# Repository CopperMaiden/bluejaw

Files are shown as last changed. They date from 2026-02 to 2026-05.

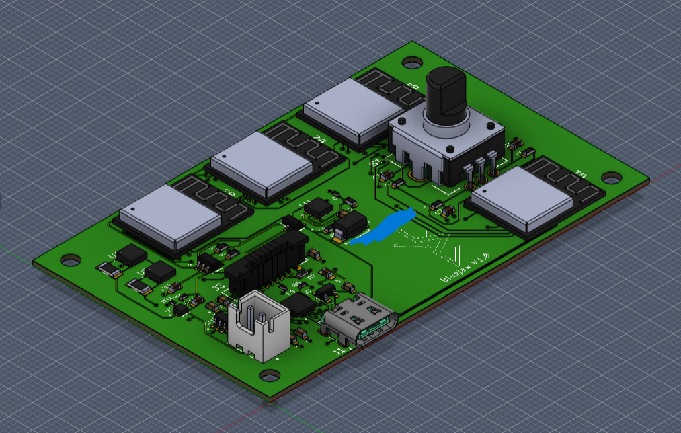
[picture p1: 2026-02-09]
Images/Screenshot 2026-02-08 093432.png

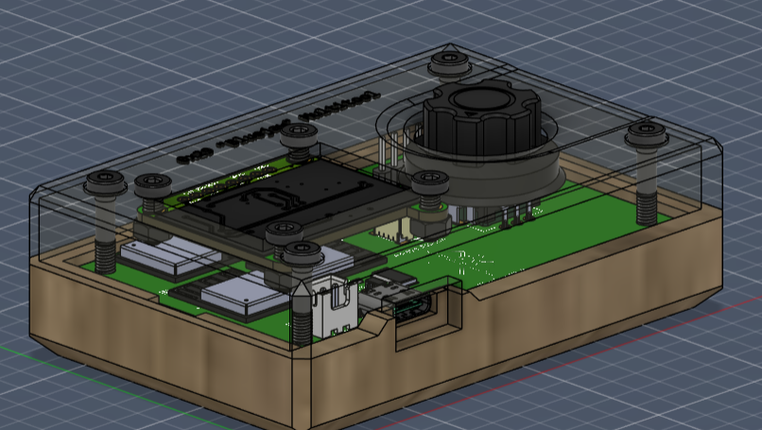
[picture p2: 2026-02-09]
Images/image.9png.png

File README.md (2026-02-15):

# BLUEJAW
Multi-client Bluetooth sharing device with a mass of QOL features, all packed into the size of an Altoids tin

Hello !
To clear up any confusion, 0x29 is just one of my aliases. This device is of my own design, yet I'm flexible regarding the public's consumption or adaptations of it. Open source is love <3.

This project is dedicated to my partner and made possible by the HackClub organization. (WEBSITE: https://hackclub.com/, © 2026 Hack Club. 501(c)(3) nonprofit (EIN: 81-2908499))

In-Progress Cad Model of Physical Design & Logo

# FILE GUIDE

```
/Documentation - All project documentation is stored here as markdown files
/Firmware-&-Software - Any files pertaining to the firmware or otherwise code written for the device
/Images - All images or screenshots taken during the course of designing this project
/Models - Any 3D models associated with the project
/PCB - GERBER file for the BLUEJAW V1.0 PCB
```

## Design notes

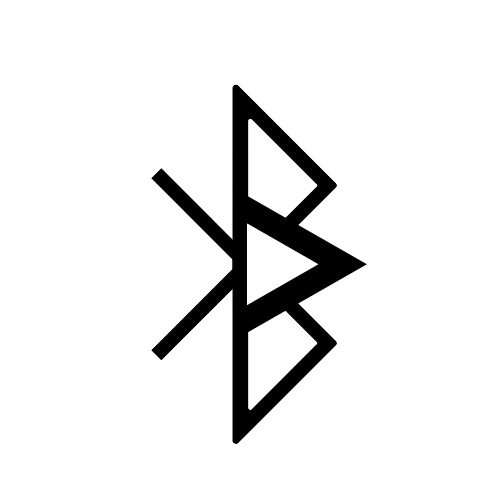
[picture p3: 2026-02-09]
Images/Untitled_design-removebg-preview.png

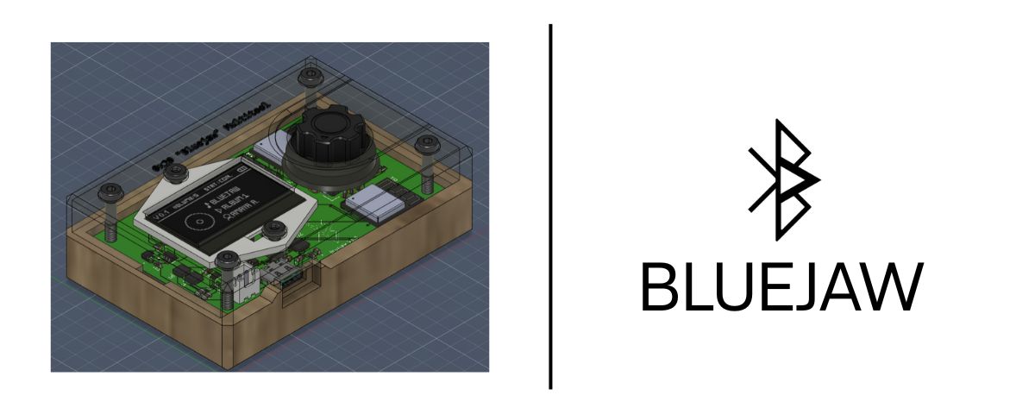
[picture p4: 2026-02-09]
Images/BLUEJAW(3).jpg

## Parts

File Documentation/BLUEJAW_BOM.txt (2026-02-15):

Partlist exported from PCB v138 at 2/15/2026 1:18 PM

Reference Designators          Quantity Description Package                   Value                          Manufacturer              Manufacturer Part Number Vendor Vendor Part Number Top/Bottom 
                               1        PCB Board   Board                                                                                                                                            
B1, B2, B3, B4                 4                    XCVR_ESP32-C3-MINI-1-N4   ESP32-C3-MINI-1-N4             Espressif Systems                                                            Top        
C1, C2, C10, C13               4                    CAPC1608X90N              CL10B105KP8NNNC                Samsung Electro-Mechanics                                                    Top        
C3, C9, C11                    3                    CAPC1608X90N              CL10A106KP8NNNC                Samsung Electro-Mechanics                                                    Top        
C5                             1                    CAPC1608X90N              CL10A475KP8NNNC                Samsung Electro-Mechanics                                                    Top        
C6                             1                    CAPC1608X90               C0603C104K5RACTU               KEMET                                                                        Top        
C7, C8, C12, C14, C15          5                    CAPC1608X90N              C0603C104K5RAC7411             Kemet                                                                        Top        
CH1                            1                    SOT95P280X145-5N          MCP73811T-420I/OT                                                                                           Top        
CR1                            1                    CR_SMA_403AE_OSI          SS14CR_SMA_403AE_OSI                                                                                        Top        
D1                             1                    SOT143                    SP0503BAHTG                                                                                                 Top        
J1                             1                    AMPHENOL_12402012E212A    12402012E212A                  Amphenol                                                                     Top        
J2                             1                    JST_B2B-XH-A              B2B-XH-A                       JST Sales America Inc.                                                       Top        
J3                             1                    AMPHENOL_F31W-1A7H1-11016 F31W-1A7H1-11016               Amphenol                                                                     Top        
MOSFET1                        1                    MICRO3_SOT23_INF          IRLML6401TRPBFMICRO3_SOT23_INF                                                                              Top        
R1, R6, R8, R10, R15, R16, R17 7                    RESC1607X60N              RC0603FR-0710KL                                                                                             Top        
R2                             1                    RESC1005X40N              CRGCQ0402F82K                                                                                               Top        
R3, R4                         2                    RES_ERA2AEB512X           ERA2AEB512X                    Panasonic                                                                    Top        
R5                             1                    RES_ERA2AEB102X           ERA2AEB102X                    Panasonic                                                                    Top        
R7                             1                    RES_ERJ-3GEYJ684V         ERJ-3GEYJ684V                  Panasonic                                                                    Top        
R9                             1                    RES_ERA2ARC512X           ERA2ARC512X                    Panasonic                                                                    Top        
R11                            1                    RES_ERA2AEB222X           ERA2AEB222X                    Panasonic                                                                    Top        
R12                            1                    RC0402FR-07330RL          RC0402FR-07330RL                                                                                            Top        
R13, R14                       2                    RESC3216X50N              RG3216P-5004-B-T1                                                                                           Top        
S1                             1                    XDCR_PEC12R-4215F-S0024   PEC12R-4215F-S0024             Bourns                                                                       Top        
U1                             1                    AMPHENOL_12402012E212A    LD39200PU33R                   ST Microelectronics                                                          Top        
U2                             1                    QFN50P400X400X80-25N      CP2102N-A02-GQFN24R            Silicon Labs                                                                 Top        
U3                             1                    SON50P150X150X80-6N       BQ29700DSER                    Texas Instruments                                                            Top        
U4, U5                         2                    TRANS_CSD16406Q3          CSD16406Q3                                                                                                  Top        
U6                             1                    SOT-23-5_MC_MCH           MCP3021A0T-E/OTSOT-23-5_MC_MCH                                                                              Top

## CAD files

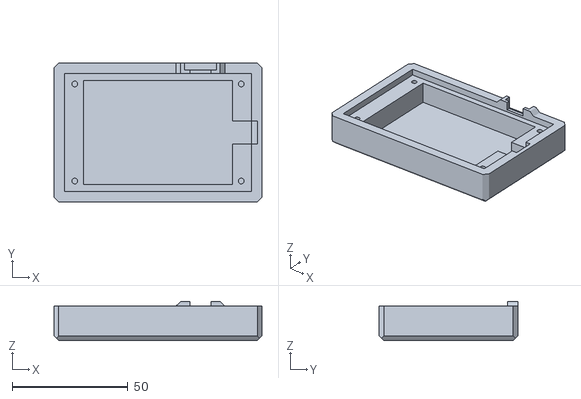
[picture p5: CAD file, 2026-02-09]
Models/BottomCase/bottomcasing.stl
90.0 x 60.0 x 16.9

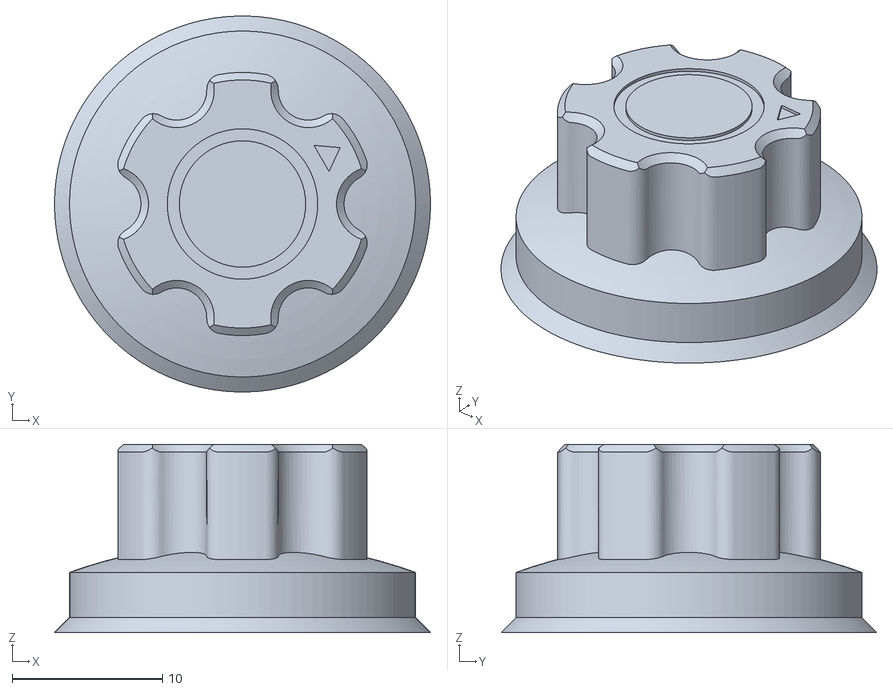
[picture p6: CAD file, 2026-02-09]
Models/Misc/BluejawInterfaceKnob.stl
25.0 x 25.0 x 12.5

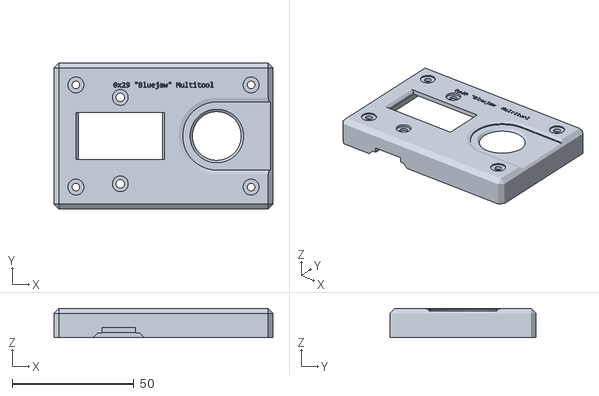
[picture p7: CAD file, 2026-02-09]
Models/TopCase/topcasing.stl
90.0 x 60.0 x 12.0

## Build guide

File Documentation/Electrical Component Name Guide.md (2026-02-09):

### All component names and their identification/serial numbers are listed below. 
(Project BLUEJAW by Amaya Allison: https://github.com/CopperMaiden/bluejaw)

---
- "12402012E212A" - USB C receptacle

- "B2B-XH-A" - JST 2 pin connector
- "BM04B-SRSS-TB" - JST 4 pin connector

- "CL10B105KP8NNNC" - CAP CER 1UF 10V X7R 0603
- "CL10A106KP8NNNC" - CAP CER 10UF 10V X5R 0603
- "C0603C104K5RAC7411" - CAP CER 0.1UF 50V X7R 0603
- "CL10A106KP8NNNC" - CAP CER 10UF 10V X5R 0603

- "ERA2AEB512X" - RES SMD 5.1K OHM 0.1%
- "ERA3AEB122V" - RES SMD 1.2K OHM 0.1%
- "RPC2512JT470R" - RES 470 OHM 5%
- "RC0603FR-0710KL" - 10 kOhms ±1% 0.1W, 1/10W Chip Resistor
- "CRGCQ0402F82K" - RES 82K OHM 1% 1/16W 0402
- "ERA-2AEB102X"  - RES SMD 1K OHM 0.1% 1/16W 0402
- "RC0603FR-0710KL" - RES 10K OHM 1% 1/10W 0603
- "ERJ-3GEYJ684V" - RES SMD 680K OHM 5% 1/10W 0603
- "ERA-2ARC512X" - RES SMD 5.1KOHM 0.25% 1/16W 0402
- "ERA-2AEB222X" - RES SMD 2.2K OHM 0.1% 1/16W 0402
- "RC0402FR-07330RL" - RES 330 OHM 1% 1/16W 0402
- "RG3216P-5004-B-T1" - RES 5M OHM 0.1% 1/5W 0805

- "ESP32-C3-MINI-1-N4" - Cmon... (minor alternative to common controllers, perfect for project)

- "MCP73811T-420I_OT" - IC BATT CNTL LI-ION 1CEL SOT23-5

- "PEC12R-4215F-S0024" - ENCODER INCRE QUAD HORIZN PC PIN

- "SOT_619TA_DIO" or "FMMT619TA" - TRANS NPN 50V 2A SOT-23-3

- "LD39200PU33R" - LINEAR VOLTAGE REGULATOR (3.3 VOLTS)

- "SP0503BAHTG" - TVS DIODE 5.5VWM 8.5VC SOT1434

- "IRLML6401TRPBF" - MOSFET P-CH 12V 4.3A SOT23

---

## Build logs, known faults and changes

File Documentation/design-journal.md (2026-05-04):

<!--
  This journal is auto generated by Hack Club Blueprint.
-->

# 2/9/2026 - Created Poster for Device  

_Time spent: 2.0h_  

Created a poster after being requested to display this project at my Highschool. The poster is attached below.

Poster

I do not have logs preceding this one, since this project had to be restarted from a prior repository. The change left a large gap in uploaded documentation, but I logged my progress elsewhere (discord channel), and will dedicate the next few days of work to transferring those updates here (while I wait for this project's PCB to arrive).  

# 2/10/2026 - Rotated assembly and shortened casing  

_Time spent: 4.3h_  

### Personal log:
I ended up having to make a redesign to the upper shell and the display tray to prevent the knob from being inaccessible, as well as effectively reduce the overall profile of the device, since it was spacially ineffecient before this revision.

# Height reduction
These images demonstrate the height reduction achieved by the redesigned upper half of the casing.



(Measurements from highest to lowest points on upper casing (8mm (new) height v. 12mm (Old) height))


---

# Update to device orientation

As a result, due to collisions, the display had to be rotated, shifting the orientation of the device entirely.


### Collisions:
Screws from display tray (hardware secures display tray to top half of the case)
After reorienting the display tray and rejointing the assembly in CAD, I noticed a glaring issue regarding collisions with components connected to the PCB. Various components would intersect the bottom of screws or nuts without adjustment. To combat this, height reduction was chosen to be done at 2/3 the height of the original top half of the device's case. Additionally, the tray was reduced in profile to avoid collision with the battery connector on the PCB, demonstrated in the image below.

(Second image shows **ORIGINAL** tray design with colliding area circled)

Decals now differ from the horizontal variation of the assembled device in CAD to the vertical variation, designated revision 1 and revision 2, respectively. (first image: revision 1, second image: revision 2).




Lastly, hardware has changed for both the display tray and the four screws securing the top and bottom halves of the device's case.
Revision 1: {Top and bottom screws: M3 x 10mm | Display tray screws: M3 x 8mm}
Revision 2: {Top and bottom screws: M3 x 6mm | Display tray screws: M3 x 14mm}

# Conclusion
The revisions were necessary to reduce the overall size of the device, but they leave room for concern. For instance, the display is now rotated 90 degrees from the connector on the PCB, which could damage the display's FPC is there is too much stress put on it during assembly. Further issues should be investigated. I will also continue to add previous design history over the course of the next few days. The PCB for bluejaw has been produced at the factory and will be ready for soldering after funding is secured for the project (since components must be ordered).  

# 2/11/2026 - PCB Design Summary (A little over 1 month)  

_Time spent: 55.0h_  

# Introduction
Accidentally, I had not stored my documentation on this platform, acting against the instruction all participants recieved for the Blueprint event. I made this mistake because I believed that the project's complexity would make it near impossible to finish given the original deadline, however I worked on it nonetheless. Now that the deadline seems feasible again, I have re-entered this event with a stricter set of goals and a half-finished device (conceptually; missing firmware).

This journal entry accounts for the roughly 2 month long period of design I allocated to creating a PCB. As of today, 2/11/2026, there is no changes to be made to the PCB of the device. The board has been ordered and is in transit. When funding is secured, the PCB can be assembled with it's necessary components.

---

The following image is verifiable proof of the date of creation for the PCB.


---

# Week 1 (Estimated ~12 hours)

With the initial design concept in mind, I took to wikipedia to research the bluetooth protocol, [found here](https://en.wikipedia.org/wiki/Bluetooth). I learned that there would need to be multiple devices with a bluetooth implementation in order for there to be multiple outputs for audio sharing. That limitation lead me to search through the electronics component distributing company, Digikey. 

In my mind, the design would center around, initially, only 3 bluetooth capable modules, which would all be made portable via a rechargeable battery. For a small, portable device, the bluetooth modules needed to meet the following criteria: 
- Energy efficient 
- Reliable 
- Tiny
- Built in microcontroller (to handle peripherals and peer communication)
- Low cost

! NOTE: (Postscript) I incorrectly recount my experience in the paragraph proceeding this note. I originally believed an RP2040 chip was the ideal microcontroller to drive the ESP-32 modules, before eventually learning that the ESP-32 modules were fully capable of acting as their own microcontrollers. END OF NOTE. !

With all of the criteria in mind, I ended up selecting the "ESP-32 C3 MINI 1 N4", a capable microcontroller with bluetooth and wifi, all in an SMD package that could interface with a PCB nicely.
MFG_ESP32-C3-MINI-1

The ESP-32 C3 draws between 290mA ~ 350mA at the most, and since there was only 3 of them (at the time), I assumed the maximum draw of current from the battery would be 1050mA, give or take. With a selected PCB size of 80mm by 50mm (about the size of an altoid's tin), the battery would need the following criteria:
- Smaller than 80mm (length) by 50mm (width)
- Near 3.3 Volts (For the ESP-32 C3)
- At least ~2 hours of battery life when running at full load

I decided on the MIKROE-1120, a 3.7 volt and 2Ah rechargeable lithium-ion battery (63.5mm x 44.2mm x 7.0mm).
MFG_MIKROE-1120

Using that battery automatically limited me to using a specific JST-style connector to power the ESP-32 modules. I arbitrarily selected the B2B-XH-A, mostly because it was a functional connector for the design's purpose (a JST connector receptacle with a pitch of 0.098" (2.50mm) and two male pins were required).

B2B-XH-A(LF)(SN)

Finally, I'd need to figure out what the user-interface would be. I knew about a cheap oled display from Adafruit, specfically the SH1106G display with the following specs:
- 128x64 resolution
- OLED
- 1.3"
- Monochrome
- SPI communication

It would be a fairly barebones component that would require my own implementation, but the cost of this raw display was significantly cheap compared to it's breakout board alternative, which was also offered by Adafruit (Raw display: $6.50 v. Finished display: $19.95).


To implement the display, I'd need the connector specified by Adafruit to connect it's FPC "ribbon" cable to the PCB of Bluejaw. Adafruit states, "for the matching connector, you'll need a 16-pin 0.5mm pitch FPC flip-lock connector" (https://www.adafruit.com/product/5228).

The connector I selected was not chosen for any other reasons besides matching the qualifications given by Adafruit. The F31W-1A7H1-11016 from Amphenol was the first result that appeared in Digikey's search engine that I found aesthetically pleasing, so I selected it.
F31W-1A7H1-11016

A display gives this device a voice, but the user still cannot interact with it until a peripheral is implemented. That's why I turned to using a rotary encoder for user-input. I searched through Digikey and initially selected the PEC12R-4225F-S0024, since it had a button and seemed relatively small (I would later find out that was not the case).
PEC12R-4217F-S0024
! NOTE: I would learn after importing this component that this image from Digikey was incorrect and highly inaccurate to the product. END OF NOTE !

To charge the battery, I chose a USB-C receptacle (arbitrarily), with the product name 12402012E212A.
12402012E212A

For the last part of the design, I knew that the battery would require some kind of IC for charge management. I searched Digikey for "battery management system" and sourced the BQ29700DSER, an IC capable of managing a single lithium ion cell.
296~4207810~DSE~6

! NOTE: The following image contains the RP2040 referenced in an earlier note. Parts of the initial design are labelled. END OF NOTE. !
anotatedFirstRevision

All of these initial components were then put onto a 80mm by 50mm rectangular PCB to see how they would be positioned.

# Week 2: Implementing major components (Estimated time: ~13 hours)

This week involved trying to integrate the components selected from the previous week to actually function. To provide an analogy, imagine writing bullet points for a creative writing piece and proceeding to flesh out each idea later on, like character names for instance, or how their backstories tie together cohesively.

### Early design of charging circuitry

To start, I tried implementing the battery charging IC by following the recommended schematic provided with it on Digikey. The first thing I did was realize that my charging IC was not, in fact, a charging IC, but instead only a battery protection IC (I would remove it only to add it back later as I realized I would need it in the final device to avoid overcurrent or undercurrent, as well as some other general hazards that come with using a lithium-ion battery.

The component I replaced the battery protection IC with was an IC I believed was capable of charging the circuit. The MCP73811T-420I/OT from Microchip Technology was labelled as a charge controller on Digikey--a component that I researched was capable of managing the current and voltage being provided to the battery during a charge cycle.
150~C04-091~CT,OT~5_web(640x640)

In this version of the PCB, I add in general components recommended by the datasheet, with the addition of a voltage divider to take 5 volts from the USB-C receptacle and turn it into a manageable 3.3 volt signal for the PROG pin on the IC (the pin required by the IC to set the target voltage for the output).


The two capacitors I used to implement the schematic shown above were both CL10B105KP8NNNC capacitors. They had a limit of 10 volts with one microfarad capacitance (per capacitor), the capacitance being the more important specification since it was the recommended schematic's only criteria for the component. Considering these were both used as decoupling capacitors, the 10% +- tolerance in their capacitance was more than negligeable.
Ceramic-Capacitor-CL-Series

As for the resistors, I attempted to find the closest difference in their resistance to still achieve a 3.3 volt output from the divider. The resistors were 470 ohms and 1.2kOhm components, respectively.
The ERA-3AEB122V was 1.2kOhms with a 0.1% tolerance, and the RPC2512JT470R was the 470ohms with 5% tolerance.
Image 1 is the ERA-3AEB122V, image 2 is the RPC2512JT470R:
10-0603 Resistor(1)
2512 (6432 Metric)

Here is an image of the PCB with this stage of implementation:
project1
! NOTE: The image also has traces from the ESP-32 modules linking them to the RP2040, this connection is not of much importance, since it's purely ground connections and linking pins with the same function together (IOVDD repeated multiple times) END OF NOTE. !

Here is an image of previous image's schematic, specifically the charging IC:


### Hardware to program the ESP-32 modules

I knew that at some point, I'd need to add a method to actually flash the firmware I write to the ESP-32 modules so they could function as intended. Since I'd used debugging header pins on previous PCBs for my projects in the past, I decided to use some male header pins that were compatible with most hobbyist breadboard-style jumper wires. My plan was to use some of my existing programming tools, like a CH340 or similar, to program each module.

I landed on a 3 pin male header with 2.54mm pitch, the 61300311121 to be exact:


Why three pins? Well, in my last project, an e-ink display controlled by a simple ATTINY1616-SN microcontroller, I used UPDI, a protocol that required 3 pins. For some reason, based off of no actual fact, I assumed that this would apply to the ESP-32 modules as well. Regardless, I changed the header later on to a 4 pin design to use UART instead. Here's an image of the three pin header on the PCB before we move on:
project2

The four pin header I switched to was not a set product, but rather a package from Fusion 360's default library, mostly as a placeholder until I could settle on a proper solution for programming the ESP-32 modules. I figured it wouldn't matter what specific header I'd purchase since they follow identical soldering footprints. The header was titled "PINHD-1X4" in software by Fusion 360.

At this point, I realized just how little I knew about what I was designing and reached out to a friend of my brother, Hailey. Hailey has a mass of skills that include: embedded circuits, low level programming, and designing PCBs, just to name a few. Hailey assisted me with verifying my ideas and implementations of various parts of the design, essentially acting as a peer reviewer for major aspects or concepts of my design.

---

### Small tangent:
It's a very crucial part of my design philosophy to avoid AI by any means necessary. While the temptation of having an immediate answer to complex questions is strong, so is my regard towards AI in projects like these: I do not believe artificial intelligence should have any presence in a design that is deeply personal to yourself and your own life. Bluejaw means a lot to me, being a project I only thought of and made possible because of my amazing partner. I wanted it to be as genuine and heartfelt as it could be, and for those reasons, I sought help from Hailey to make sure things would go smoothly.

---

You may realize the RP2040 is no longer present in the last image of Bluejaw given in this document, and that's intentional. Hailey pointed out that the ESP-32 was more than capable of acting as it's own microcontroller, so I supplemented the component with another ESP-32, giving the device even more potential for multi-client output. 

Some minor rearrangement of components later, and this was the result:
project4
You may notice two additional components, those are SMD resistors linked to the USB-C receptacle to enable 5V charging & cause the device to act as a sink for power, instead of giving it.


Both of those resistors are ERA2AEB512X resistors, with 5.1kOhm resistance and 0.1% tolerance.
ERAW Series 0402 Pkg

# Weeks 3 + 4: Heavy integration of all components (Estimated time ~20 hours)

At this point, momentum took off with how fast I began to implement each part of the circuit. The project went from a "maybe" into a "I need this done, or else.", and I was (and still am) determined to make the latter work.

There were a few major categories of integration to name here:
- Charging/Battery protection
- Programming solution over UART from USB-C to ESP-32 modules
- ESP-32 peer to peer communication (communication between modules)
- Integrating peripherals (USB-C receptacle, rotary encoder, display connector)

### Charging/Battery protection

A problem exists when both the USB-C receptacle and battery can actively provide power to the restof the circuits at the same time. To fix it, I added a transistor that would cut the battery off whenever power could be supplied from the USB-C port instead. Here's an image of the schematic with that implementation.


But, as you may immediately notice, as did I a few minutes after adding the transistor, it would not function as intended at all. The way that the transistor is wired in this schematic achieves nothing, and only makes the problem worse. For context, the label marked "BAT" is the output that the rest of the circuit would use from the battery as power. If the transistor were implemented as shown in the schematic, it would prevent the battery from providing any power, and additionally have a useless gate that opens to nothing if power is added via the USB-C receptacle. Regardless, I knew I'd need a different cut-off solution, so I moved onto another part of the design to step away and give myself time to think. The transistor I used was the FMMT619TA, picture shown below.
31~SOT23-3~F,N,SA~3

To combat the difference between the battery's 3.7 volts and the USB-C receptacle's 5 volts, a linear regulator was added: an LD39200PU33R. The IC is capable of a 2A output at 3.3 volts, a perfect solution for the device's 3.3 volt requirement from the ESP-32 modules. Previous estimation of current draw from the ESP-32 modules was done with only three modules, but there are four. Current draw from four ESP-32 modules can be estimated with 350mA * 4 = 1400mA, which would be within the limits of the regulator. The 2A output of this linear regulator is not strictly enforced, but rather just a limit. The device would output a steady 3.3 volts for the ESP-32 modules with leeway for additional peripherals (like the display).
497~7946637~~6

Here's an early implementation of the regulator without the battery connected:


The following components are referenced in the schematic above (may not be in the final implementation):
R1 = 10kOhm resistor, part of a voltage divider (RC0603FR-0710KL)
R2 = 82kOhm, also part of a voltage divider (CRGCQ0402F82K)
C3 = 10uF, decoupling cap (CL10A106KP8NNNC)
C4 = 10uF, decoupling cap (CL10A106KP8NNNC)

After realizing my previous error with the regulator, I turned to Hailey for suggestions. She sent me a Hackaday article with many important tips and a wealth of information regarding charging circuits and the general use of lithium ion cells in projects: https://hackaday.com/2022/10/10/lithium-ion-battery-circuitry-is-simple/

The following schematic was recommended as a solution from the article to the charging cut-off problem I recognized previously:
hadimg_liion_electronics_7

I then implemented it with the regulator, as the article suggested, and was left with this completed solution:


The combination of Hailey's advice and the new information I gathered form the Hackaday article taught me that I'd need a few more circuits to prevent any issues with the battery, such as overcharge or undercharge. Simply put, it would charge, but without any safety or protections aside from some loose guardrails.

Back came the single-cell lithium-ion battery protection IC from earlier: The BQ29700DSER


The following components are referenced in the schematic above:
R11 = 2.2kOhm resistors with 0.1% tolerance (ERA2AEB222X) PURPOSE: Recommended by datasheet
R12 = 330Ohm resistor with 1% tolerance (RC0402FR-07330RL) PURPOSE: Recommended by datasheet
R13, R14 = 5MOhm resistors with 0.1% tolerance (RG3216P-5004-B-T1) PURPOSE: Recommended by datasheet (mention in footnote: "The 5-M resistor for an external gate-source is optional.")
C14 = 0.1uF capacitor (C0603C104K5RAC7411) PURPOSE: Recommended by datasheet
U4, U5 = N-Channel mosfet (CSD16406Q3) PURPOSE: Recommended by datasheet

This circuit would help cut the battery off from the rest of the circuit in the case of any of the following faults:
- Over current
- Over/Under voltage
- Short circuit

Recommended circuit from the datasheet:


Lastly, I wanted the device to have some way to indicate to the user when a charge was necessary, and to give myself the opportunity to implement a low-power mode in software to preserve the battery whenever the charge would run low. I learned about analog to digital converters from Hailey and implemented the following circuit:


Connections were made to a child ESP-32 device with the intention of being co0ntrolled by the parent ESP-32 in addressed commands to read the ADC (analog to digital converter). Specific child device in question was designation B2.

The following components are referenced in the schematic above:
C15 = 0.1uF (C0603C104K5RAC7411) PURPOSE: Decoupling capacitor
R16, R17 = 10kOhm resistors with 1% tolerance (RC0603FR-0710KL) PURPOSE: Pull up resistors (Recommended by datasheet)

An analog to digital converter allows the main ESP-32 of Bluejaw to read the change in voltage from the battery as it slowly drops during usage. When the voltage gets lower, the ESP-32 will be able to detect that change via the converter, and the menu can give an estimation for the current capacity/charge of the lithium-ion cell (at max charge battery sits around 4.2 volts, at min battery sits around 2.75 volts (Assumed from battery cut off circuits in datasheet)).

### Programming solution over UART from USB-C to ESP-32 Modules

Taking inspiration from a video I saw (credits to the RF-Clown V2 from CiferTech (https://youtu.be/Jadzrg9bz40?si=hG7vkoj-3Ku74Nmk) https://github.com/cifertech/RF-Clown), I realized that I could use a UART bridge IC to make communication between the USB-C receptacle and the ESP-32 modules possible. Ironically enough, the RF-Clown V2 is a very similar device to Bluejaw, but this is unintentional. The RF-Clown V2 is an elegant design that efficiently utilizes all of it's components; Bluejaw is an idea I got off a whim while with my partner that spiraled into a much larger project than intended. Here is the bridge IC I decided to use after reviewing the schematics from the RF-Clown V2 (CP2102N-A02-GQFN24R):
336~24QFN-,90-4x4~M~24_web(640x640)

And here is an image of the circuit I implemented with the RF-Clown V2 as heavy inspiration (USB-C present):


The following components are referenced in the schematic above (may not be in the final implementation):
R5 = 1kOhm resistor with 0.1% tolerance, (ERA-2AEB102X) PURPOSE: Power supply for IC, recommended by datasheet of IC
R4, R3 = 5.1kOhm resistors with 0.1% tolerance, (ERA-2AEB512X) PURPOSE: Pull down for USB-C, same purpose as mentioned earlier to enable sink from receptacle at 5V
C5 = 4.7uF capacitor (CL10A475KP8NNNC) PURPOSE: Decoupling cap, recommended by datasheet of IC
C6 = 0.1uF capacitor (C0603C104K5RACTU) PURPOSE: Decoupling cap, recommended by datasheet of IC
D1 = diode IC with 1 input, 3 outputs (SP0503BAHTG) PURPOSE: ESD protection diodes, recommended by datasheet of IC
12402012E212A = (USB-C receptacle, mentioned in prior texts of this document)

This will allow me to implement the communication required for the ESP-32 modules in software later, significantly reducing the complexity of translating the datapins of the USB-C receptacle into something usable.

### ESP-32 peer to peer communication (communication between modules)

UART is a more than capable serial communication protocol for this project, with some minor modifications in firmware to give it multi-device capability. While it's slower than I2C or SPI, it works nicely with an IC that helps the USB-C receptacle communicate in UART, reducing the overall complexity I'd have to deal with if I used a different protocol, at least on the hardware side of things.

An early implementation of UART involved connecting each ESP-32 module to a single ESP-32 module that would act as the parent, however, as you will see in the image below, I initially connected all of the transmit and recieve lines together, until I could decide which module was the most ideal to select as the parent with additional components added to the board.


In the final implementation, I used B1 as the parent ESP-32, using the others as secondary modules to recieve commands as child devices.

Child devices are capable of communicating with the parent through unique connections (UART1, UART2, UART3).

The MASTER_UART connections all lead off the parent ESP-32, as it would address each child individually with universal messages. The firmware for each child will be different depending on the presence of peripherals, with individual addresses given by flashing the modules individually before soldering to the PCB. In a later revision, if there is enough funding, I will seek to implement this solution instead, such that individual addressing is easier:


I sadly neglected to make this change before ordering the PCBs with the original connectivity, so this will have to be a decision in the future when funding is available. Just in case, I updated the design in CAD such that this may be an immediate solution to utilize in the case that it becomes necessary:


To share audio reliably, the I2S protocol was implemented for every device with three pins per module. I learned about it while researching serial protocols earlier in the project and thought it might add some nice reliablity to the audio sharing capabilities of the device, such that the UART method of communication would not be over-burdoned. (https://www.digikey.com/en/maker/tutorials/2023/what-is-the-i2s-communication-protocol)

The following pins are required for a minimalistic implementation of I2S, and are the ones I used here:
- BCLK (bit clock)
- LRCLK (left-right clock)
- SD/DIN (serial data/data in/data out)

### Integrating peripherals (USB-C receptacle, rotary encoder, display connector)

The rotary encoder was slightly more challenging to implement, since Hailey and I had a few conversations regarding the matter of having to implement the component from the ground up. Unlike some encoders, the one used in this project would need many external components for reliability and basic function.


It seemed relatively simple to me at first, wire the internal switch to the GPIO of the module, same as the A and B channels of the encoder. But the circuit shown above would not be reliable.
By the later end of designing the PCB, the following circuit was used:


There is a variety of decoupling capacitors and pull up resistors for both the A and B channels, as well as the internal switch of the rotary encoder.

The following components are referenced in the schematic:
R6, R8, R10 = 10kOhm with 1% tolerance, resistors (RC0603FR-0710KL) PURPOSE: Pull up resistors
C7, C8, C12 = 0.1uF, capacitors (C0603C104K5RAC7411) PURPOSE: Decoupling capacitors

Although I struggled to understand how a rotary encoder worked in software, Hailey managed to explain the offset of the A and B channels and how they can be used to determine rotational movement and its direction. Here's an image she sent of her oscilloscope demonstrating the difference between the channels.


Essentially, one channel will make metal on metal contact with the internals before the other during rotational movement, connecting ground to the power supplied at the encoder's channels. Depending on which channel is active first, rotational direction can be determined. You can then use the amount of connections in a set interval that occur to determine the speed of rotation, for instance, if the channel was triggered 10 times in one second versus 20 times in one second. However, speed is not that important in this implementation, as the firmware of this device should merely interpret every connection as a signal to iterate through various menus.

The USB-C receptacle required integration with the linear regulator, a UART bridge, a cut-off circuit for charging, and some minor components to accompany each part of those connections (as previously shown in documentation). If you are curious about the specifics of integration, consult the other categories in this section of the log and their associated schematics. They will be marked with a "(USB-C present)" postscript for easier searching.

The analog to digital converter is technically a peripheral for the device, and thus will be referenced here, but specifics still associate more closely with the battery, so all details regarding it's implementation will be found under that category instead.

As for the display, the SH1106G, I took to a project from Adafruit for reference regarding implementation. A project was included in the product description of the display with a schematic of a custom numpad that used the SH1106G. Using the schematic, I managed to replicate my own implementation for Bluejaw:


The following components are referenced in the schematic above:
C10, C13 = 1uF with 10% tolerance, capacitors (CL10B105KP8NNNC) PURPOSE: Recommended bridging between pins from schematic
C9, C11 = 10uF capacitors (CL10A106KP8NNNC) PURPOSE: Decoupling capacitors
R9 = 5.1kOhms with 0.25% tolerance, resistor (ERA2ARC512X) PURPOSE: Pull up resistor
R7 = 680kOhms with 5% tolerance, resistor (ERJ-3GEYJ684V) PURPOSE: Pull up resistor

Connections were made to a single ESP-32 child device with the intentions of controlling this peripheral by extension of the parent ESP-32 sending commands to it's child. Specific ESP-32 child device in question is designation B3.

(Adafruit's schematic):


# CONCLUSIONS

The design seems promising overall, apart from the minor shortsighted decision to manufacture the boards with a shared line of communication in UART instead of individual addressing. I'm fairly certain I can manage to implement everything I intended in software, which, speaking of, I have compiled a list for:
# Deliveries (MVP)
- Bluetooth audio sharing
	- Single host (audio input) to multiple clients (audio output)
	- Basic media controls (Pausing, play, rewind, skip, volume)
	- Transfer media player metadata for display
	- Individual client device volume adjustment
	- Source volume adjustment
	- EQ Adjustment (low, mid, high (Make some frequencies louder than others))
	- Resync clients option (Set to automatic with user specified time interval or manual resync)
	
- Cute as &#$@ (censored for professionalism) display (User interface)
	- 128x64 pixels
	- Expect 60-120 fps
	- Animation toggle between "cutesy" and "HARDCOREEE" (Playful menu item names) (fluid animations on or off)
	- Record with like pulsing graphics on title screen (default screen)
	- Primary screen should idle on the title screen (music details and basic controls)
	- Secondary screen reserved for settings with multiple submenus
	- Battery percentage displayed at top left corner at all times
	- Top menu bar for device specific data: battery, bluetooth connectivity status, etc.
	- Settings includes category to select individual client device settings
	- Progress bar for music (Customizable, IF time allows during development)
	
- The dial of doom AKA "D.O.D." (Rotary encoder)
	- Volume adjustment between 0-11
	- Volume displayed as a number with other device specific data at top right
	- Used for all menu interactions and value adjustments, as well as device power on and off states 
	
# QOL suggestions (Implement if time allows):
	- Volume increment control (Allows user to fine tune volume increments of the 0-11 scale)
	- Battery saving idle screen (Toggleable in settings, if enabled, screen turns off after 10 seconds of inactivity and wakes with a press of the encoder, time is adjustable)
	- When on very, very low battery, overly dramatic countdown starts until the device powers off
	- Third "custom" option for animations/transitions to toggle specific animations as desired
	- Resyncing has a symbol at the top menu bar when active
	- Individual client delay compensation (Client setting to add a delay for slower devices)
	- ! SYNCING WILL BE REQUIRED FOR I2S, UART, AND BLUETOOTH !

---

THIS CONCLUDES DOCUMENTATION FOR PCB DESIGN AS OF 2/15/2026, FILES AVAILABLE AT REPO:
https://github.com/CopperMaiden/bluejaw  

# 2/15/2026 - Programming Firmware  

_Time spent: 2.0h_  

# Introduction

This journal entry provides complete context and historical record of the design that went into making the firmware for Bluejaw.

---

Recall the ESP32-C3-MINI-1-N4 modules used for the only PCB in this project. Since these microcontrollers act as the heart of the device, controlling peripherals and making bluetooth audio sharing possible on a larger scale, the code will primarily revolve around designing firmware that achieves the necessary functions outlined in a previous journal entry.



The four modules you see in the schematic above all have a unique quality to them. 
- B1: (Parent module) Has the responsiblity of controlling all child ESP-32 devices, as well as reading the rotary encoder, and using UART communication from the bridge IC to recieve firmware updates.
- B2: (Child module) Interpret or otherwise pass on the reading from the analog to digital converter attached to it's GPIO
- B3: (Child module) Control the display and update as instructed by the parent ESP-32 module
- B4: (Child module) No attached peripherals or additional responsibility

So, with four unique devices, a different set of instructions will be required of each device.

To program the microcontrollers, a slight alternative solution to regular UART connections is required, as the USB to UART bridge IC is only connected to B1, the parent ESP-32 module. I imagined using B1 as a messenger to flash the other three devices, since the capability of being able to individually address them could make it possible. I'd merely need to find a way to implement communication in firmware that allows the parent ESP-32 to act as a middle-man when flashing new updates to the four microcontrollers.

In PlatformIO, an embedded system development ecosystem, I was able to define different primary source files for each ESP32 module.


Note that the baud rate is defined here as well. I selected 9600 as the baud rate for both monitoring in the terminal and uploading, purely because I thought it'd be reliable, but I could definitely go faster, considering the USB to UART bridge IC's 3 megabaud limit.

I can almost guarentee at this point that my next place of research should be the associated documentation for the ESP32's developer docs [located here](https://docs.espressif.com/projects/esp-idf/en/stable/esp32/index.html), but I wanted to take notes on the documentation of the actual microcontroller I'm using first. I neglected to do this in the past, and I hypothesize that my PCB design suffered as a result of unnecessary or lacking features.

---

### Notes extracted from ESP32-C3-MINI-1 datasheet:

**The following information was gathered if considered important to Bluejaw's functions:**

When programming in UART, a mode titled "Joint-Download Mode" must be enabled with three strapping pins:


This allows a connection with the module's UART0 interface which can then be used to upload and send debug messages back to the programmer (which I will definitely be making use of). Specifically, messages caused by code in ROM can use the UART0 interface to communicate with the programmer.

"In Joint Download Boot mode, users can download binary files into flash using UART0 or USB interface. It is also possible to download binary files into SRAM and execute it from SRAM"

- 5MB maximum speed for UART interfaces (there are two: UART0, UART1)

(This explains how the chip is able to communicate with a device like a laptop so long as the laptop can also speak in "UART". The ESP32 and the laptop can "share" a language by both using UART, which they do, thanks to the USB to UART bridge I implemented previously on the PCB.)

- There are two onboard analog to digital converters from the ESP32, but luckily my manual implementation of an ADC is still necessary, since the documentation seems to imply there would be additional configuration required to make the onboard ADCs accurate in their readings.

Power consumption of different modes in miliamps (used in previous calculations for the battery of the PCB):


---  

# 2/24/2026 - Programming Firmware  

_Time spent: 2.0h_  

# Introduction

This journal entry provides complete context and historical record of the design that went into making the firmware for Bluejaw.

---

Recall the ESP32-C3-MINI-1-N4 modules used for the only PCB in this project. Since these microcontrollers act as the heart of the device, controlling peripherals and making bluetooth audio sharing possible on a larger scale, the code will primarily revolve around designing firmware that achieves the necessary functions outlined in a previous journal entry.



The four modules you see in the schematic above all have a unique quality to them. 
- B1: (Parent module) Has the responsiblity of controlling all child ESP-32 devices, as well as reading the rotary encoder, and using UART communication from the bridge IC to recieve firmware updates.
- B2: (Child module) Interpret or otherwise pass on the reading from the analog to digital converter attached to it's GPIO
- B3: (Child module) Control the display and update as instructed by the parent ESP-32 module
- B4: (Child module) No attached peripherals or additional responsibility

So, with four unique devices, a different set of instructions will be required of each device.

To program the microcontrollers, a slight alternative solution to regular UART connections is required, as the USB to UART bridge IC is only connected to B1, the parent ESP-32 module. I imagined using B1 as a messenger to flash the other three devices, since the capability of being able to individually address them could make it possible. I'd merely need to find a way to implement communication in firmware that allows the parent ESP-32 to act as a middle-man when flashing new updates to the four microcontrollers.

In PlatformIO, an embedded system development ecosystem, I was able to define different primary source files for each ESP32 module.


Note that the baud rate is defined here as well. I selected 9600 as the baud rate for both monitoring in the terminal and uploading, purely because I thought it'd be reliable, but I could definitely go faster, considering the USB to UART bridge IC's 3 megabaud limit.

I can almost guarentee at this point that my next place of research should be the associated documentation for the ESP32's developer docs [located here](https://docs.espressif.com/projects/esp-idf/en/stable/esp32/index.html), but I wanted to take notes on the documentation of the actual microcontroller I'm using first. I neglected to do this in the past, and I hypothesize that my PCB design suffered as a result of unnecessary or lacking features.

---

### Notes extracted from ESP32-C3-MINI-1 datasheet:

**The following information was gathered if considered important to Bluejaw's functions:**

When programming in UART, a mode titled "Joint-Download Mode" must be enabled with three strapping pins:


This allows a connection with the module's UART0 interface which can then be used to upload and send debug messages back to the programmer (which I will definitely be making use of). Specifically, messages caused by code in ROM can use the UART0 interface to communicate with the programmer.

"In Joint Download Boot mode, users can download binary files into flash using UART0 or USB interface. It is also possible to download binary files into SRAM and execute it from SRAM"

- 5MB maximum speed for UART interfaces (there are two: UART0, UART1)

(This explains how the chip is able to communicate with a device like a laptop so long as the laptop can also speak in "UART". The ESP32 and the laptop can "share" a language by both using UART, which they do, thanks to the USB to UART bridge I implemented previously on the PCB.)

- There are two onboard analog to digital converters from the ESP32, but luckily my manual implementation of an ADC is still necessary, since the documentation seems to imply there would be additional configuration required to make the onboard ADCs accurate in their readings.

Power consumption of different modes in miliamps (used in previous calculations for the battery of the PCB):


---

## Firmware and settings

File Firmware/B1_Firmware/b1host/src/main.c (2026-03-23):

#include "driver/uart.h"
#include "driver/gpio.h"
#include "driver/i2s_std.h"
#include "esp_event.h"
#include "nvs_flash.h"
#include "esp_log.h"
#include "esp_nimble_hci.h"
#include "nimble/nimble_port.h"
#include "nimble/nimble_port_freertos.h"
#include "host/ble_hs.h"
#include "services/gap/ble_svc_gap.h"
#include "sdkconfig.h"

static int ble_gap_event(struct ble_gap_event *event, void *arg);
void serialCommsSetup(void);
void bleSetup(void);

void app_main() {

    // Start UART and i2s communication
    // TODO: Figure out how to loop UART RX and TX pin switching alongside other tasks
    serialCommsSetup();

    // Startup BLE with GAP service to search available sources
    bleSetup();
}

// B2 -> B3 -> B4
const int RX_PINS[3] = {0, 5, 6};
const int TX_PINS[3] = {1, 3, 4};

void serialCommsSetup(void){
    // UART CONFIG (b1 to b3 connection)
    const uart_port_t uart_num = UART_NUM_1;

    uart_config_t uart_config = {
        .baud_rate = 115200,
        .data_bits = UART_DATA_8_BITS,
        .parity    = UART_PARITY_DISABLE,
        .stop_bits = UART_STOP_BITS_1,
        .flow_ctrl = UART_HW_FLOWCTRL_DISABLE
    };

    ESP_ERROR_CHECK(uart_param_config(uart_num, &uart_config));

    ESP_ERROR_CHECK(uart_set_pin(
        uart_num,
        GPIO_NUM_1,                      // TX pin (choose valid GPIO)
        GPIO_NUM_0,                      // RX pin (choose valid GPIO)
        UART_PIN_NO_CHANGE,      // RTS not used
        UART_PIN_NO_CHANGE       // CTS not used
    ));

    ESP_ERROR_CHECK(uart_driver_install(
        uart_num,
        1024,   // RX buffer
        1024,   // TX buffer
        0,
        NULL,
        0
    ));
    // END OF UART CONFIG

    
    // START OF i2s CONFIG
    // Transmit from B1
    i2s_chan_handle_t tx_handle;

    // Explicit configuration
    i2s_chan_config_t chan_cfg = {
        .id = I2S_NUM_0,
        .role = I2S_ROLE_MASTER,
        .dma_desc_num = 6,
        .dma_frame_num = 240
    };

    // Create channel
    ESP_ERROR_CHECK(i2s_new_channel(&chan_cfg, &tx_handle, NULL)); // No RX necessary

    // Set to std mode in 16 bit slots with bclk, ws, and serial data pins (also LR audio)
    i2s_std_config_t std_cfg = {
        .clk_cfg = I2S_STD_CLK_DEFAULT_CONFIG(44100),
        .slot_cfg = I2S_STD_MSB_SLOT_DEFAULT_CONFIG(I2S_DATA_BIT_WIDTH_16BIT, I2S_SLOT_MODE_STEREO),
            .gpio_cfg = {
            .mclk = I2S_GPIO_UNUSED,
            .bclk = GPIO_NUM_7,
            .ws = GPIO_NUM_8,
            .dout = GPIO_NUM_9,
            .din = I2S_GPIO_UNUSED,
        },
    };

    // Init + enable new channel
    ESP_ERROwR_CHECK(i2s_channel_init_std_mode(tx_handle, &std_cfg));
    ESP_ERROR_CHECK(i2s_channel_enable(tx_handle));
    // END OF i2s CONFIG
}

// Global event handler for BLE (CHANGE LATER FOR ACTUAL IMPLEMENATION, THIS IS FROM SIMS YT TUTORIAL)
static int ble_gap_event(struct ble_gap_event *event, void *arg)
{
    struct ble_hs_adv_fields fields;

    switch (event->type)
    {
    // NimBLE event discovery
    case BLE_GAP_EVENT_DISC:
        ESP_LOGI("GAP", "GAP EVENT DISCOVERY");
        ble_hs_adv_parse_fields(&fields, event->disc.data, event->disc.length_data);
        if (fields.name_len > 0)
        {
            printf("Name: %.*s\n", fields.name_len, fields.name);
        }
        break;
    default:
        break;
    }
    return 0;
}

void bleSetup(void){
    // START OF BLUETOOTH LOW ENERGY (NimBLE) SETUP
    // Create tag for host identity and a var for address (auto assign later)
    char *TAG = "Bluejaw";
    uint8_t ble_addr_type;

    struct ble_gap_disc_params disc_params;

    disc_params.filter_duplicates = 1;
    disc_params.passive = 0;
    disc_params.itvl = 0;
    disc_params.window = 0;
    disc_params.filter_policy = 0;
    disc_params.limited = 0;

    // Subroutine for discovery mode of ble
    ble_gap_disc(ble_addr_type, 10000, &disc_params, ble_gap_event, NULL);
    
    // Required by BLE to store connection information
    nvs_flash_init();

    // Activate host controller interface
    esp_nimble_hci_init();
    nimble_port_init();

    // Configure device name characteristic, then init GAP service
    ble_svc_gap_device_name_set("Bluejaw");
    ble_svc_gap_init();

    // Assign address
    ble_hs_id_infer_auto(0, &ble_addr_type);
    // END OF BLE SETUP
}

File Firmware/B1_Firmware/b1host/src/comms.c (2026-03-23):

#include "comms.h"

#include <string.h>
#include "freertos/FreeRTOS.h"
#include "freertos/task.h"
#include "esp_err.h"
#include "esp_log.h"

static const char *TAG = "comms";

// Internal state
static poll_state_t s_poll = {
    .current_module_index = 0,
    .module_ids = {MODULE_B2_ADC, MODULE_B3_DISPLAY, MODULE_B4_ENCODER},
    .rx_pins = {B2_RX_PIN, B3_RX_PIN, B4_RX_PIN},
    .tx_pins = {B2_TX_PIN, B3_TX_PIN, B4_TX_PIN}
};

// Most recent readings to be written by poll task (read by application layer)
static adc_data_t s_latest_adc = {0};
static encoder_data_t s_latest_encoder = {0};

// CRC-8 (Polynomial 0x07, init 0x00)
uint8_t comms_cr8(const uint8_t *data, size_t len){
    uint8_t crc = 0x00;
    for (size_t i = 0; i < len; i++){
        crc ^= data[i];
        for (int bit = 0; bit < 8; bit++){
            if (crc & 0x80) {
                crc = (crc << 1) ^ 0x07;
            } else {
                crc <<= 1;
            }
        }
    }
    return crc;
}

// UART Initialization
void comms_init(void){
    uart_config_t cfg = {
        .baud_rate = 115200,
        .data_bits = UART_DATA_8_BITS,
        .parity = UART_PARITY_DISABLE,
        .stop_bits = UART_STOP_BITS_1,
        .flow_ctrl = UART_HW_FLOWCTRL_DISABLE
    };

    ESP_ERROR_CHECK(uart_param_config(UART_NUM, &cfg));

    // Starts on child module B2
    ESP_ERROR_CHECK(uart_set_pin(
        UART_NUM,
        s_poll.tx_pins[0],
        s_poll.rx_pins[0],
        UART_PIN_NO_CHANGE,
        UART_PIN_NO_CHANGE
    ));

    ESP_ERROR_CHECK(uart_driver_install(
        UART_NUM,
        1024,
        1024,
        0,
        NULL,
        0
    ));

    ESP_LOGI(TAG, "UART Initialized, starting on B2 (ADC)");

    // Task set to priority 5, prevent unresponsive behavior with other tasks alongside it (i2s, BLE)
    // Round robin poll task
    xTaskCreate(comms_poll_task, "comms_pull", 4096, NULL, 5, NULL);
}

// Pin switching (For UART, since there's only one port available)
void comms_switch_to_module(uint8_t module_index){
    // Flush any remaining data before pin reassignment
    uart_flush(UART_NUM);

    ESP_ERROR_CHECK(uart_set_pin(
        UART_NUM,
        s_poll.tx_pins[module_index],
        s_poll.rx_pins[module_index],
        UART_PIN_NO_CHANGE,
        UART_PIN_NO_CHANGE
    ));

    ESP_LOGD(TAG, "Switched to module 0x%02X (TX=%d, RX=%d)",
        s_poll.module_ids[module_index],
        s_poll.tx_pins[module_index],
        s_poll.rx_pins[module_index]
    );
}

// Turn packet struct into 8-byte buffer for transmission
static void packet_to_bytes(const comms_packet_t *p, uint8_t out[PACKET_LEN]){
    out[0] = p->start;
    out[1] = p->module_id;
    out[2] = p->cmd;
    memcpy(&out[3], p->payload, PACKET_PAYLOAD_LEN);
    out[7] = p->crc8;
}

// Turn 8-byte buffer into packet struct for recieving
static void bytes_to_packet(const uint8_t in[PACKET_LEN], comms_packet_t *out){
    out->start = in[0];
    out->module_id = in[1];
    out->cmd = in[2];
    memcpy(out->payload, &in[3], PACKET_PAYLOAD_LEN);
    out->crc8 = in[7];
}

// Compute CRC for all bytes except the 8th
static uint8_t packet_crc(const comms_packet_t *p){
    uint8_t buf[PACKET_LEN - 1];
    buf[0] = p->start;
    buf[1] = p->module_id;
    buf[2] = p->cmd;
    memcpy(&buf[3], p->payload, PACKET_LEN);
    return comms_cr8(buf, sizeof(buf));
}

void comms_build_poll(comms_packet_t *out, uint8_t module_id){
    memset(out, 0, sizeof(out));
    out->start = PACKET_START_BYTE;
    out->module_id = module_id;
    out->cmd = CMD_POLL;
    out->crc8 = packet_crc(out);
}

void comms_build_display_cmd(comms_packet_t *out, uint8_t sub_cmd, const uint8_t args[3]){
    memset(out, 0, sizeof(*out));
    out->start        = PACKET_START_BYTE;
    out->module_id    = MODULE_B3_DISPLAY;
    out->cmd          = CMD_DISPLAY_WRITE;
    out->payload[0]   = sub_cmd;
    out->payload[1]   = args[0];
    out->payload[2]   = args[1];
    out->payload[3]   = args[2];
    out->crc8         = packet_crc(out);
}

void comms_build_display_clear(comms_packet_t *out) {
    memset(out, 0, sizeof(*out));
    out->start = PACKET_START_BYTE;
    out->module_id = MODULE_B3_DISPLAY;
    out->cmd = CMD_DISPLAY_CLEAR;
    out-> crc8 = packet_crc(out);
}

// Send and recieve logic
esp_err_t comms_send_packet(const comms_packet_t *packet) {
    uint8_t buf[PACKET_LEN];
    packet_to_bytes(packet, buf);
    
    int written = uart_write_bytes(UART_NUM, (const char *)buf, PACKET_LEN);
    if (written != PACKET_LEN) {
        ESP_LOGE(TAG, "UART write failed: wrote %d of %d bytes", written, PACKET_LEN);
        return ESP_FAIL;
    }
    return ESP_OK;
}

esp_err_t comms_recv_packet(comms_packet_t *out_packet) {
    uint8_t buf[PACKET_LEN];
    int timeout_ticks = pdMS_TO_TICKS(POLL_TIMEOUT_MS);

    int received = uart_read_bytes(UART_NUM, buf, PACKET_LEN, timeout_ticks);

    if(received != PACKET_LEN) {
        ESP_LOGW(TAG, "Timeout or short read: got %d bytes", received);
        return ESP_ERR_TIMEOUT;
    }

    // Validate start byte
    if(buf[0] != PACKET_START_BYTE) {
        ESP_LOGW(TAG, "Bad start byte: 0x%02X", buf[0]);
        uart_flush_input(UART_NUM);
        return ESP_ERR_INVALID_RESPONSE;
    }

    bytes_to_packet(buf, out_packet);

    // Validate CRC
    uint8_t expected_crc = packet_crc(out_packet);
    if (out_packet->crc8 != expected_crc) {
        ESP_LOGW(TAG, "CRC mismatch: got 0x%02X, expected 0x%02X", out_packet->crc8, expected_crc);
        return ESP_ERR_INVALID_CRC;
    }

    return ESP_OK;
}

// Response processing
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

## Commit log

2026-02-09 Add existing project files to repo
    [BluejawInterfaceKnob.stl, bottomcasing.stl, topcasing.stl]
2026-02-15 Added bill of materials
2026-03-08 B1 flashing stage firmware (to B3)
